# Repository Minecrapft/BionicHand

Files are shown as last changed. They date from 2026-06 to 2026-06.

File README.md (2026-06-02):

# Robohand

A simple Arduino sketch to control a robotic hand (servo-based) — provided as `Robohand.ino`.

## Summary

This project contains an Arduino sketch that reads inputs (sensors/buttons/potentiometers) and drives servos to move a robotic hand. Use this README to set up the hardware, upload the sketch, and customize pin mappings or servo ranges.

## Files

- `Robohand.ino` — main Arduino sketch (open in Arduino IDE).

## Required Hardware

- Arduino board (Uno, Nano, Mega, etc.)
- 3–5 x hobby servos (depending on hand design)
- Power supply for servos (separate 5–6V recommended)
- Jumper wires, breadboard
- Optional: potentiometers, push buttons, flex sensors for control

## Wiring (example)

- Connect servo signal wires to Arduino digital pins (example):
  - Thumb: D3
  - Index: D5
  - Middle: D6
  - Ring: D9
  - Pinky: D10
- Connect servo power (V+) and ground to the servo power supply. Connect servo ground to Arduino GND.
- Connect control inputs (potentiometers or buttons) to analog pins A0–A2 as needed.

Adjust pin numbers in `Robohand.ino` to match your wiring.

## Software & Upload

1. Install the Arduino IDE from https://arduino.cc.
2. Open `Robohand.ino` in the Arduino IDE.
3. Select the correct board and port under `Tools` → `Board` / `Port`.
4. Connect the Arduino via USB and click Upload.

If using external servo power, ensure the external supply is connected and common-grounded with the Arduino before powering servos.

## Usage

- Once uploaded, control the hand using the configured inputs (potentiometers/buttons). The sketch maps inputs to servo positions; modify the mapping in the code if needed.

## Customization

- Open `Robohand.ino` and edit pin definitions and servo limits to match your hardware.
- Calibrate servo min/max values to prevent mechanical binding.

## Troubleshooting

- Servos jittering: provide a stable external power supply and common ground.
- Servo not moving: check signal pin, correct power, and that the sketch references the correct pin.

## Contact

If you want help customizing the sketch or wiring, open an issue or reply here.

## ESP32-S3 (connection & run)

This sketch can run on an ESP32-S3-based board with a few small changes. Follow these steps to connect and upload:

1. Install ESP32 board support in the Arduino IDE:
  - Open `Tools` → `Board` → `Boards Manager` and install the "esp32" package by Espressif.
2. Power and wiring:
  - Servos typically need 5V. Use a separate 5–6V servo power supply and connect all grounds together (ESP32 GND ↔ servo power GND).
  - Connect each servo signal wire to a free ESP32-S3 GPIO. Example (change pins in the sketch to match):
    - Thumb: GPIO 18
    - Index: GPIO 19
    - Middle: GPIO 21
    - Ring: GPIO 22
    - Pinky: GPIO 23
  - Avoid pins reserved for flash/SPI (commonly GPIO6–GPIO11) and consult your board's pinout for S3-specific restrictions.
3. Library and code changes:
  - If `Robohand.ino` uses the AVR `Servo.h`, switch to an ESP32-compatible servo library such as `ESP32Servo` (install via Library Manager) or use a PWM/i2c driver (PCA9685) for many servos.
  - Update the pin definitions at the top of `Robohand.ino` to the GPIOs you wired.
  - Ensure servo pulse limits are appropriate for your servos (calibrate `min`/`max` values to avoid binding).
4. Uploading the sketch:
  - In Arduino IDE select `Tools` → `Board` → `ESP32S3 Dev Module` (or the specific board name) and the correct `Port`.
  - Click Upload. If required, press the boot/enable buttons as prompted by the IDE.
5. Troubleshooting & tips:
  - If servos twitch or reset the board, power them from a dedicated supply and keep a common ground.
  - For many servos, using a dedicated PWM driver (PCA9685) reduces load on the ESP32 and simplifies timing.
  - Use the Serial Monitor to view debug messages; set the baud rate in the sketch to match (commonly 115200).

These steps should get `Robohand.ino` running on an ESP32-S3 board. If you want, I can update `Robohand.ino` to include `ESP32Servo` examples and default ESP32 pin definitions.

## Control via Phone (Web Interface)

To control the robot hand from your phone using a web browser on the local network:

### Setup

1. **Connect ESP32-S3 to WiFi:**
   - Add WiFi credentials to `Robohand.ino`:
     ```cpp
     const char* ssid = "YOUR_WIFI_SSID";
     const char* password = "YOUR_WIFI_PASSWORD";
     ```
   - Initialize WiFi in `setup()`:
     ```cpp
     WiFi.begin(ssid, password);
     while (WiFi.status() != WL_CONNECTED) {
       delay(500);
     }
     Serial.println(WiFi.localIP());
     ```
   - Note the IP address printed to the Serial Monitor (e.g., `192.168.1.100`).

2. **Create a simple web server:**
   - Add these includes at the top of `Robohand.ino`:
     ```cpp
     #include <WiFi.h>
     #include <WebServer.h>
     ```
   - Create a WebServer instance:
     ```cpp
     WebServer server(80);  // Listen on port 80 (HTTP)
     ```
   - In `setup()`, define a handler that serves an HTML control panel:
     ```cpp
     server.on("/", HTTP_GET, []() {
       String html = "<html><body style='font-family:Arial'>"
         "<h1>Robohand Control</h1>"
         "<button onclick=\"fetch('/servo?pin=18&pos=90')\">Thumb Open</button>"
         "<button onclick=\"fetch('/servo?pin=18&pos=0')\">Thumb Close</button><br>"
         "<button onclick=\"fetch('/servo?pin=19&pos=90')\">Index Open</button>"
         "<button onclick=\"fetch('/servo?pin=19&pos=0')\">Index Close</button><br>"
         "</body></html>";
       server.send(200, "text/html", html);
     });
     ```
   - Add a servo control endpoint:
     ```cpp
     server.on("/servo", HTTP_GET, []() {
       int pin = server.arg("pin").toInt();
       int pos = server.arg("pos").toInt();
       // Attach servo and move to position
       // (details depend on your Servo library)
       server.send(200, "text/plain", "OK");
     });
     ```
   - Start the server in `setup()`:
     ```cpp
     server.begin();
     ```
   - In `loop()`, handle incoming requests:
     ```cpp
     server.handleClient();
     ```

3. **Access from your phone:**
   - Connect your device to the **`RoboHand-S3`** WiFi network (password: `12345678`).
   - Open a web browser and navigate to: **`http://192.168.4.1`**
   - No port number needed — it runs on port 80 (standard HTTP), so the browser uses it automatically.
   - You should see the Robohand control panel with buttons to open/close fingers.

4. **Customize the web interface:**
   - Add sliders for smooth servo control:
     ```html
     <input type="range" min="0" max="180" value="90" 
       onchange="fetch('/servo?pin=18&pos=' + this.value)">
     ```
   - Add visual feedback (color change, status display) using JavaScript.

### Troubleshooting

- **Phone can't find the ESP32:** Ensure both phone and ESP32-S3 are on the same WiFi network.
- **Web page doesn't load:** Check the IP address from the Serial Monitor (e.g., 192.168.1.), and make sure no firewall is blocking port 80.
- **Servos don't respond:** Verify the `/servo` endpoint is correctly wired to your servo control code.

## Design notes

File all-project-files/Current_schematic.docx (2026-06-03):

SCHEMATIC DIAGRAM

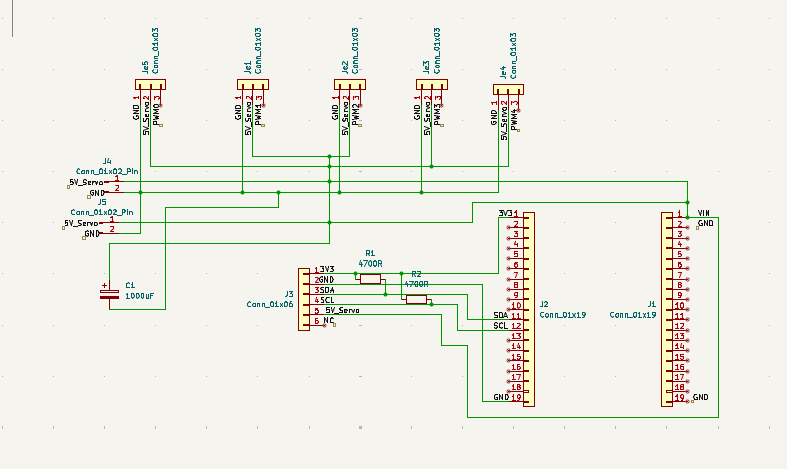
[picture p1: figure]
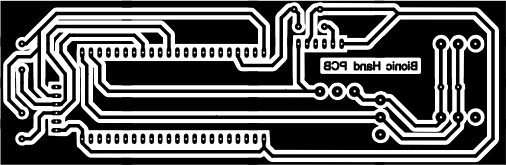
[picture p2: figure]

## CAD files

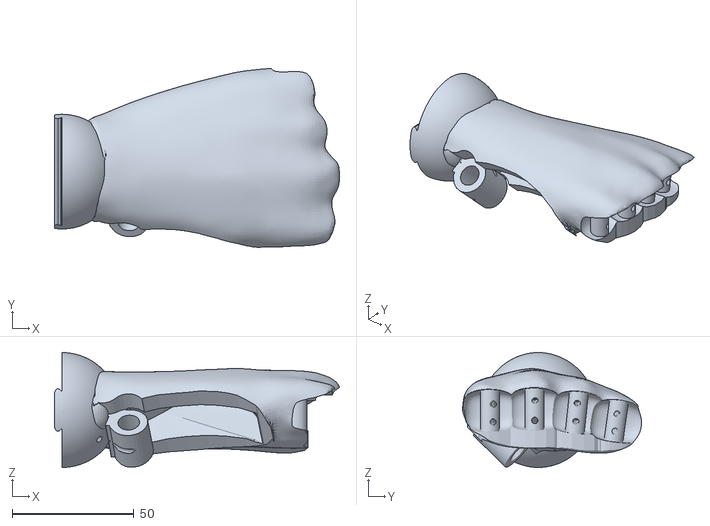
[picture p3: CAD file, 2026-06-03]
all-project-files/bionic_hand-stl-files/bionic_hand__1.stl
116.8 x 73.4 x 47.2

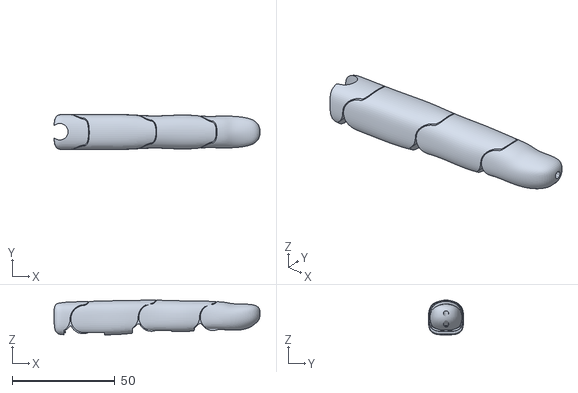
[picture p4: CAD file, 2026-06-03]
all-project-files/bionic_hand-stl-files/bionic_hand__13.stl
100.2 x 17.2 x 16.9

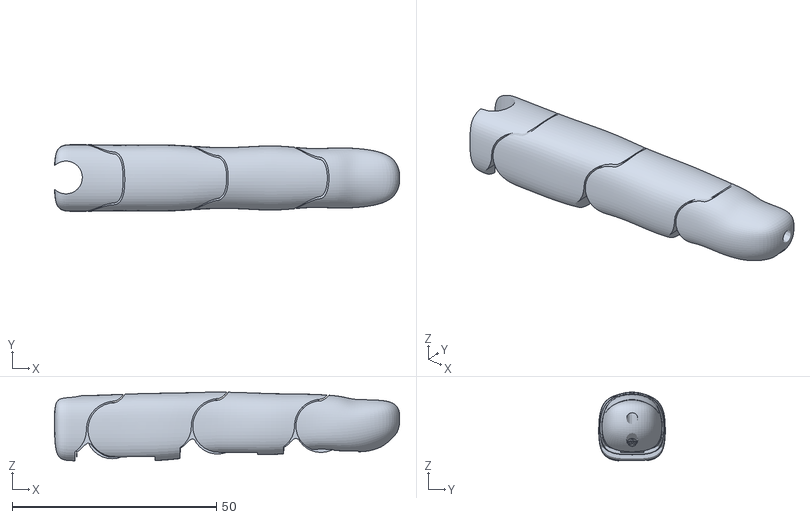
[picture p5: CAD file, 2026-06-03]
all-project-files/bionic_hand-stl-files/bionic_hand__16.stl
84.5 x 16.3 x 16.9

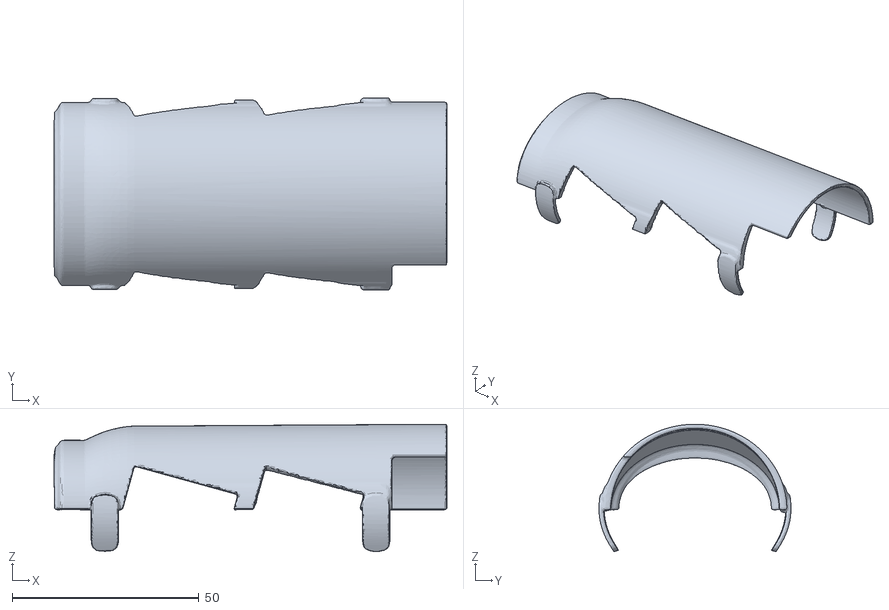
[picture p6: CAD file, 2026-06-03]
all-project-files/bionic_hand-stl-files/bionic_hand__3.stl
105.3 x 51.4 x 34.1

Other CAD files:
all-project-files/bionic_hand-stl-files/bionic_hand__14.stl
all-project-files/bionic_hand-stl-files/bionic_hand__15.stl

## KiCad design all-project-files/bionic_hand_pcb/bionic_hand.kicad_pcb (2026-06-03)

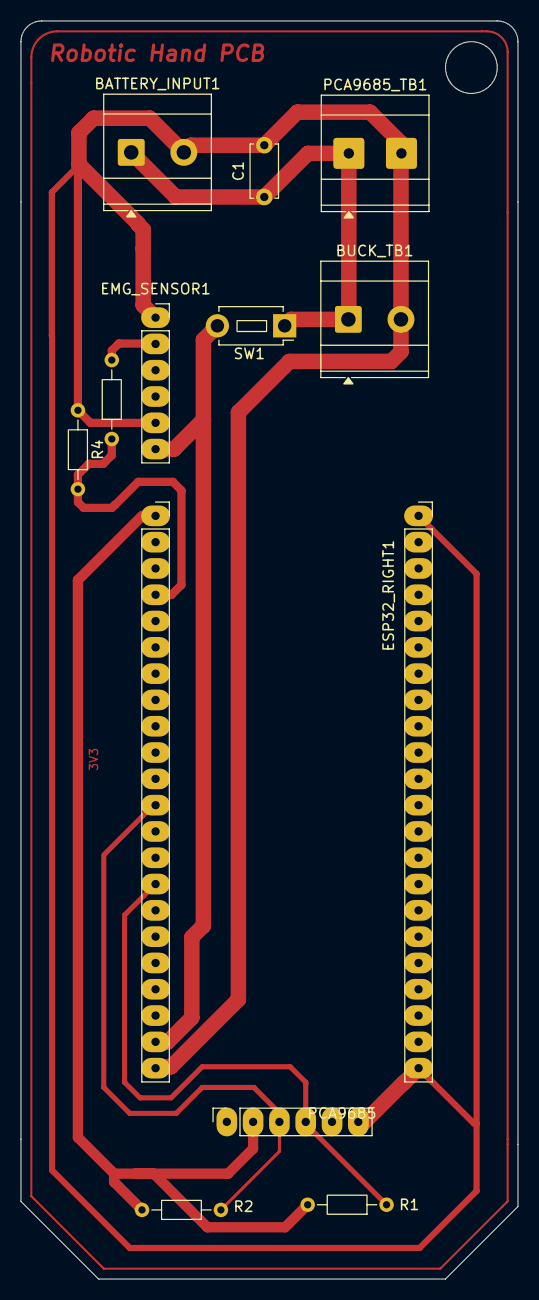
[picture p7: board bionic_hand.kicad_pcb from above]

Board: 2 copper layers, 48.0 x 121.5 mm, 13 parts (0 on the bottom side), 7 nets.

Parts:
BATTERY_INPUT1: Screw_Terminal_01x02; TerminalBlock_MetzConnect_Type073_RT02602HBLU_1x02_P5.08mm_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
BUCK_TB1: Screw_Terminal_01x02; TerminalBlock_MetzConnect_Type073_RT02602HBLU_1x02_P5.08mm_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
C1: 470u; C_Disc_D5.0mm_W2.5mm_P5.00mm
EMG_SENSOR1: Conn_01x06; PinSocket_1x06_P2.54mm_Vertical
ESP32_LEFT1, ESP32_RIGHT1: Conn_01x22; PinSocket_1x22_P2.54mm_Vertical
PCA9685: Conn_01x06; PinSocket_1x06_P2.54mm_Vertical
PCA9685_TB1: Screw_Terminal_01x02; TerminalBlock_MetzConnect_Type073_RT02602HBLU_1x02_P5.08mm_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
R1, R2, R3: 10k; R_Axial_DIN0204_L3.6mm_D1.6mm_P7.62mm_Horizontal
R4: 20k; R_Axial_DIN0204_L3.6mm_D1.6mm_P7.62mm_Horizontal
SW1: SW_DPST_x2; SW_PUSH_1P1T_6x3.5mm_H4.3_APEM_MJTP1243

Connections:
3V3: ESP32_LEFT1.1, PCA9685.2, R1.2, R2.2
5Vin: BATTERY_INPUT1.1, BUCK_TB1.1, C1.1, EMG_SENSOR1.6, ESP32_LEFT1.21, PCA9685_TB1.1, SW1.1 (A), SW1.2 (B)
/SIG: EMG_SENSOR1.2, R3.2
CMN_GND: BATTERY_INPUT1.2, BUCK_TB1.2, C1.2, EMG_SENSOR1.1, EMG_SENSOR1.5, ESP32_LEFT1.22, ESP32_RIGHT1.1, ESP32_RIGHT1.22, PCA9685.6, PCA9685_TB1.2, R4.1
GPIO4: ESP32_LEFT1.4, R3.1, R4.2
GPIO8: ESP32_LEFT1.12, PCA9685.3, R2.1
GPIO9: ESP32_LEFT1.15, PCA9685.4, R1.1

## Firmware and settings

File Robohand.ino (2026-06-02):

#include <Arduino.h>
#include <WiFi.h>
#include <WebServer.h>
#include <Preferences.h>
#include <Wire.h>
#include <Adafruit_PWMServoDriver.h>

#define NUM_SERVOS   5
#define MAX_PRESETS  16   // max stored presets
#define MAX_STEPS    20   // max steps per preset

const char* ssid     = "RoboHand-S3";
const char* password = "12345678";

Adafruit_PWMServoDriver pwm = Adafruit_PWMServoDriver(0x40);

int  currentAngles[NUM_SERVOS]      = {0,   0,   0,   0,   0};
int  calibrationOffsets[NUM_SERVOS] = {0,   0,   0,   0,   0};

int  servoMin[NUM_SERVOS]           = {150, 150, 150, 150, 150};
int  servoMax[NUM_SERVOS]           = {600, 600, 600, 600, 600};
int  servoMaxAngle[NUM_SERVOS]      = {180, 180, 180, 180, 180};
int  servoSpeed[NUM_SERVOS]         = {0, 0, 0, 0, 0};
bool servoReversed[NUM_SERVOS]      = {false, false, false, false, false};
char servoLabels[NUM_SERVOS][16]    = {"Thumb","Index","Middle","Ring","Pinky"};

float currentPhysicalAngles[NUM_SERVOS] = {0, 0, 0, 0, 0};
unsigned long lastUpdateTime = 0;

// ── Preset data structures ──────────────────────────────────────────────────
struct PresetStep {
  int  angles[NUM_SERVOS]; // target angle for each servo
  int  speed;              // deg/sec for this step (0 = instant)
  int  holdMs;             // how long to hold after reaching position (ms)
};

struct Preset {
  bool       used;
  char       name[24];
  int        stepCount;
  PresetStep steps[MAX_STEPS];
};

Preset presets[MAX_PRESETS];

// ── Preset playback state ───────────────────────────────────────────────────
bool     presetRunning    = false;
int      presetRunId      = -1;
int      presetRunStep    = -1;
unsigned long presetHoldEnd = 0;        // millis when current hold expires
bool     presetMoving     = false;      // waiting for servos to reach target
int      presetSpeedOverride[NUM_SERVOS]; // per-step speed stored here
int      presetTargets[NUM_SERVOS];       // current step's angle targets

WebServer server(80);
Preferences prefs;

// ══════════════════════════════════════════════════════════════════════════════
//  HTML / CSS / JS  (single embedded page)
// ══════════════════════════════════════════════════════════════════════════════
const char INDEX_HTML[] = R"rawliteral(
<!DOCTYPE html>
<html lang="en">
<head>
<meta charset="UTF-8"/>
<meta name="viewport" content="width=device-width,initial-scale=1,user-scalable=no"/>
<title>RoboHand Controller</title>
<style>
:root{--bg:#05111f;--s1:#0d1f35;--s2:#152840;--ac:#00d4ff;--pu:#7c3aed;--tx:#e2e8f0;--mu:#64748b;--ok:#22c55e;--er:#ef4444;--wa:#f59e0b;--bd:#1e3a5f}
*{box-sizing:border-box;margin:0;padding:0;-webkit-tap-highlight-color:transparent}
body{font-family:-apple-system,BlinkMacSystemFont,'Segoe UI',sans-serif;background:var(--bg);color:var(--tx);min-height:100vh}
.hdr{background:linear-gradient(135deg,var(--s1),var(--s2));padding:16px 20px;display:flex;align-items:center;justify-content:space-between;border-bottom:1px solid var(--bd);position:sticky;top:0;z-index:99}
.hdr-title{font-size:20px;font-weight:800;background:linear-gradient(135deg,var(--ac),var(--pu));-webkit-background-clip:text;-webkit-text-fill-color:transparent;background-clip:text}
.hdr-sub{font-size:12px;color:var(--mu);display:flex;align-items:center;gap:6px}
.dot{width:8px;height:8px;border-radius:50%;background:var(--ok);animation:blink 2s infinite;display:inline-block}
@keyframes blink{0%,100%{opacity:1}50%{opacity:.3}}
.tabs{display:flex;background:var(--s1);border-bottom:1px solid var(--bd);overflow-x:auto}
.tab{flex:1;min-width:70px;padding:14px 8px;text-align:center;font-size:13px;font-weight:600;color:var(--mu);cursor:pointer;border-bottom:3px solid transparent;transition:.2s;white-space:nowrap}
.tab.on{color:var(--ac);border-color:var(--ac)}
.pane{display:none}.pane.on{display:block}
.wrap{padding:14px;max-width:560px;margin:0 auto}
/* ── Quick Actions ── */
.qa{display:grid;grid-template-columns:repeat(3,1fr);gap:10px;margin-bottom:16px}
.qb{background:var(--s1);border:1px solid var(--bd);border-radius:16px;padding:14px 8px;text-align:center;cursor:pointer;transition:.15s;user-select:none}
.qb:active{transform:scale(.93);background:var(--s2)}
.qb .ico{font-size:26px;line-height:1.2}
.qb .lbl{font-size:11px;font-weight:600;color:var(--mu);margin-top:4px}
.qb.hi{border-color:var(--ac)}.qb.hi .lbl{color:var(--ac)}
/* ── Finger cards ── */
.fc{display:flex;flex-direction:column;gap:12px}
.fcard{background:var(--s1);border:2px solid var(--bd);border-radius:20px;padding:18px;transition:border-color .3s}
.fcard.lit{border-color:var(--ac)}
.fhdr{display:flex;align-items:center;justify-content:space-between;margin-bottom:14px}
.fbadge{width:36px;height:36px;border-radius:10px;display:flex;align-items:center;justify-content:center;font-weight:800;font-size:15px;color:#fff;flex-shrink:0;margin-right:10px}
.fname{font-size:16px;font-weight:700}
.fsub{font-size:12px;color:var(--mu);margin-top:2px}
.anum{font-size:24px;font-weight:800;color:var(--ac);min-width:56px;text-align:right}
input[type=range]{-webkit-appearance:none;appearance:none;width:100%;height:8px;background:var(--s2);border-radius:999px;outline:none;margin:6px 0;display:block}
input[type=range]::-webkit-slider-thumb{-webkit-appearance:none;width:28px;height:28px;border-radius:50%;background:linear-gradient(135deg,var(--ac),var(--pu));cursor:pointer;box-shadow:0 0 10px #00d4ff55}
input[type=range]:active::-webkit-slider-thumb{box-shadow:0 0 20px #00d4ffaa}
.row{display:flex;align-items:center;gap:10px;margin-top:10px}
.sbtn{width:44px;height:44px;border-radius:12px;border:1px solid var(--bd);background:var(--s2);color:var(--tx);font-size:22px;font-weight:700;cursor:pointer;display:flex;align-items:center;justify-content:center;transition:.15s;flex-shrink:0;user-select:none;line-height:1}
.sbtn:active{background:var(--ac);color:#000}
.hint{flex:1;text-align:center;color:var(--mu);font-size:11px}
/* ── Calibrate ── */
.ccard{background:var(--s1);border:1px solid var(--bd);border-radius:18px;padding:18px;margin-bottom:12px}
.chdr{display:flex;align-items:center;justify-content:space-between;margin-bottom:12px}
.cname{font-weight:600;font-size:15px}
.obadge{border-radius:8px;padding:5px 12px;font-size:14px;font-weight:700;background:var(--s2);color:var(--mu)}
.obadge.pos{color:var(--ok)}.obadge.neg{color:var(--er)}
.rst{width:100%;padding:16px;background:linear-gradient(135deg,var(--ac),var(--pu));border:none;border-radius:14px;color:#fff;font-weight:700;font-size:16px;cursor:pointer;margin-top:4px}
.rst:active{opacity:.8}
/* ── Config ── */
.cfcard{background:var(--s1);border:1px solid var(--bd);border-radius:18px;padding:18px;margin-bottom:12px}
.cfhdr{display:flex;align-items:center;gap:10px;margin-bottom:14px}
.fl{font-size:11px;color:var(--mu);font-weight:600;margin-bottom:5px}
.tinp{width:100%;padding:10px 12px;background:var(--s2);border:1px solid var(--bd);border-radius:10px;color:var(--tx);font-size:14px;outline:none;margin-bottom:12px}
.tinp:focus{border-color:var(--ac)}
.g2{display:grid;grid-template-columns:1fr 1fr;gap:10px;margin-bottom:12px}
.ninp{width:100%;padding:10px 8px;background:var(--s2);border:1px solid var(--bd);border-radius:10px;color:var(--tx);font-size:14px;outline:none;text-align:center}
.ninp:focus{border-color:var(--ac)}
.trow{display:flex;align-items:center;justify-content:space-between;margin-bottom:14px}
.trow span{font-size:14px}
.togbtn{padding:7px 16px;border-radius:8px;border:1px solid var(--bd);background:var(--s2);color:var(--mu);font-size:13px;font-weight:600;cursor:pointer;transition:.2s}
.togbtn.on{background:var(--ac);color:#000;border-color:var(--ac)}
.scfg{width:100%;padding:13px;background:linear-gradient(135deg,var(--ac),var(--pu));border:none;border-radius:12px;color:#fff;font-weight:700;font-size:14px;cursor:pointer}
.scfg:active{opacity:.8}
/* ══ PRESETS TAB ══════════════════════════════════════════════════════════ */
.pst-toprow{display:flex;gap:10px;margin-bottom:14px;margin-top:14px}
.pst-newbtn{flex:1;padding:13px;background:linear-gradient(135deg,var(--ac),var(--pu));border:none;border-radius:14px;color:#fff;font-weight:700;font-size:14px;cursor:pointer}
.pst-newbtn:active{opacity:.8}
.pst-list{display:flex;flex-direction:column;gap:10px}
.pst-card{background:var(--s1);border:1px solid var(--bd);border-radius:18px;padding:16px;display:flex;align-items:center;gap:12px}
.pst-card.running{border-color:var(--ok);box-shadow:0 0 12px #22c55e33}
.pst-icon{width:44px;height:44px;border-radius:12px;background:var(--s2);display:flex;align-items:center;justify-content:center;font-size:22px;flex-shrink:0}
.pst-info{flex:1;min-width:0}
.pst-name{font-weight:700;font-size:15px;white-space:nowrap;overflow:hidden;text-overflow:ellipsis}
.pst-meta{font-size:11px;color:var(--mu);margin-top:3px}
.pst-btns{display:flex;gap:7px;flex-shrink:0}
.ic-btn{width:38px;height:38px;border-radius:10px;border:1px solid var(--bd);background:var(--s2);color:var(--tx);font-size:17px;cursor:pointer;display:flex;align-items:center;justify-content:center;transition:.15s}
.ic-btn:active{opacity:.7}
.ic-btn.run{background:#0f3d1a;border-color:var(--ok);color:var(--ok)}
.ic-btn.edit{background:#0d2040;border-color:var(--ac);color:var(--ac)}
.ic-btn.del{background:#3d0f0f;border-color:var(--er);color:var(--er)}
.ic-btn.stop{background:#3d1f00;border-color:var(--wa);color:var(--wa)}
/* ── Preset Editor ── */
.pe-back{display:flex;align-items:center;gap:8px;margin-bottom:14px;cursor:pointer;color:var(--ac);font-weight:600;font-size:14px;margin-top:14px}
.pe-back:active{opacity:.7}
.pe-namebox{background:var(--s1);border:1px solid var(--bd);border-radius:16px;padding:16px;margin-bottom:12px}
.pe-steps{display:flex;flex-direction:column;gap:10px;margin-bottom:12px}
.step-card{background:var(--s1);border:2px solid var(--bd);border-radius:18px;padding:16px;position:relative}
.step-card.active-step{border-color:var(--ok)}
.step-hdr{display:flex;align-items:center;justify-content:space-between;margin-bottom:12px}
.step-num{width:30px;height:30px;border-radius:8px;background:var(--pu);display:flex;align-items:center;justify-content:center;font-weight:800;font-size:13px;color:#fff;flex-shrink:0}
.step-title{font-weight:700;font-size:14px;flex:1;margin-left:8px}
.step-del{width:30px;height:30px;border-radius:8px;border:1px solid var(--er);background:#3d0f0f;color:var(--er);font-size:16px;cursor:pointer;display:flex;align-items:center;justify-content:center}
.step-del:active{opacity:.6}
.step-grid{display:grid;grid-template-columns:1fr 1fr;gap:8px;margin-bottom:10px}
.sg-cell{background:var(--s2);border:1px solid var(--bd);border-radius:10px;padding:10px;display:flex;flex-direction:column;gap:4px}
.sg-lbl{font-size:10px;color:var(--mu);font-weight:600}
.sg-val{font-size:18px;font-weight:800;color:var(--ac);text-align:center}
.sg-rng{width:100%;-webkit-appearance:none;appearance:none;height:6px;background:var(--bg);border-radius:999px;outline:none}
.sg-rng::-webkit-slider-thumb{-webkit-appearance:none;width:22px;height:22px;border-radius:50%;background:linear-gradient(135deg,var(--ac),var(--pu));cursor:pointer}
.step-timing{display:grid;grid-template-columns:1fr 1fr;gap:8px}
.st-cell{background:var(--s2);border:1px solid var(--bd);border-radius:10px;padding:10px}
.st-lbl{font-size:10px;color:var(--mu);font-weight:600;margin-bottom:4px}
.st-inp{width:100%;background:transparent;border:none;color:var(--tx);font-size:16px;font-weight:700;text-align:center;outline:none}
.add-step-btn{width:100%;padding:13px;background:var(--s1);border:2px dashed var(--bd);border-radius:14px;color:var(--mu);font-weight:600;font-size:14px;cursor:pointer;transition:.2s}
.add-step-btn:hover{border-color:var(--ac);color:var(--ac)}
.add-step-btn:active{opacity:.7}
.pe-save{width:100%;padding:15px;background:linear-gradient(135deg,var(--ac),var(--pu));border:none;border-radius:14px;color:#fff;font-weight:700;font-size:16px;cursor:pointer;margin-top:6px}
.pe-save:active{opacity:.8}
.pe-run{width:100%;padding:13px;background:linear-gradient(135deg,#166534,#15803d);border:none;border-radius:14px;color:#fff;font-weight:700;font-size:14px;cursor:pointer;margin-top:8px}
.pe-run:active{opacity:.8}
/* step move arrows */
.step-arrows{display:flex;gap:4px}
.arr-btn{width:26px;height:26px;border-radius:6px;border:1px solid var(--bd);background:var(--s2);color:var(--mu);font-size:13px;cursor:pointer;display:flex;align-items:center;justify-content:center}
.arr-btn:active{background:var(--ac);color:#000}
/* status pill */
.status-pill{position:fixed;bottom:18px;left:50%;transform:translateX(-50%);background:var(--s1);border:1px solid var(--bd);border-radius:999px;padding:8px 20px;font-size:13px;font-weight:600;color:var(--mu);transition:.3s;z-index:200;pointer-events:none;opacity:0}
.status-pill.show{opacity:1}
.status-pill.ok{border-color:var(--ok);color:var(--ok)}
.status-pill.er{border-color:var(--er);color:var(--er)}
.status-pill.ru{border-color:var(--wa);color:var(--wa)}
</style>
</head>
<body>
<div class="hdr">
  <div class="hdr-title">&#129302; RoboHand</div>
  <div class="hdr-sub"><span class="dot"></span>192.168.4.1</div>
</div>
<div class="tabs">
  <div class="tab on"  id="tab-ctrl" onclick="sw('ctrl')">&#9654; Control</div>
  <div class="tab"     id="tab-pst"  onclick="sw('pst')">&#127381; Presets</div>
  <div class="tab"     id="tab-cal"  onclick="sw('cal')">&#9881; Calibrate</div>
  <div class="tab"     id="tab-cfg"  onclick="sw('cfg')">&#9965; Configure</div>
</div>

<!-- ════ CONTROL PANE ════ -->
<div id="pane-ctrl" class="pane on">
  <div class="wrap">
    <div class="qa" style="margin-top:14px">
      <div class="qb" onclick="setAll(0)"><div class="ico">&#x270A;</div><div class="lbl">Fist 0&#176;</div></div>
      <div class="qb hi" onclick="setAll(90)"><div class="ico">&#x1F590;</div><div class="lbl">Home 90&#176;</div></div>
      <div class="qb" onclick="setAll(180)"><div class="ico">&#x1F44B;</div><div class="lbl">Open 180&#176;</div></div>
    </div>
    <div class="fc" id="fingerCards"></div>
  </div>
</div>

<!-- ════ PRESETS PANE ════ -->
<div id="pane-pst" class="pane">
  <div id="pst-list-view">
    <div class="wrap">
      <div class="pst-toprow">
        <button class="pst-newbtn" onclick="newPreset()">&#43; New Preset</button>
      </div>
      <div class="pst-list" id="pstList"></div>
    </div>
  </div>
  <div id="pst-editor-view" style="display:none">
    <div class="wrap">
      <div class="pe-back" onclick="closeEditor()">&#8592; Back to Presets</div>
      <div class="pe-namebox">
        <div class="fl">Preset Name</div>
        <input type="text" class="tinp" id="pe-name" maxlength="23" placeholder="e.g. Wave Hello" style="margin-bottom:0"/>
      </div>
      <div class="pe-steps" id="peSteps"></div>
      <button class="add-step-btn" onclick="addStep()">&#43; Add Step</button>
      <button class="pe-save" onclick="savePreset()" style="margin-top:14px">&#10003; Save Preset</button>
      <button class="pe-run"  onclick="runEditorPreset()">&#9654; Save &amp; Run</button>
    </div>
  </div>
</div>

<!-- ════ CALIBRATE PANE ════ -->
<div id="pane-cal" class="pane">
  <div class="wrap">
    <div style="margin-top:14px" id="calCards"></div>
    <button class="rst" onclick="resetOffsets()">&#8635; Reset All Offsets to 0</button>
  </div>
</div>

<!-- ════ CONFIGURE PANE ════ -->
<div id="pane-cfg" class="pane">
  <div class="wrap" style="margin-top:14px" id="cfgCards"></div>
</div>

<div class="status-pill" id="statusPill"></div>

<script>
var NAMES  = ["Thumb","Index","Middle","Ring","Pinky"];
var COLORS = ["#00d4ff","#7c3aed","#10b981","#f59e0b","#f43f5e"];
var ABBR   = ["T","I","M","R","P"];
var MAX_ANGLES = [180,180,180,180,180];
var state  = {angles:[0,0,0,0,0], offsets:[0,0,0,0,0]};
var tmr    = null;
var revState = [false,false,false,false,false];

// ── Preset editor state ──────────────────────────────────────────────────────
var editingId  = -1;     // -1 = new preset
var editSteps  = [];     // array of {angles:[5], speed:int, holdMs:int}
var runningId  = -1;

// ════════════════════════════════════════════════════════════════════════════
//  TAB SWITCHER
// ════════════════════════════════════════════════════════════════════════════
function sw(name){
  ['ctrl','pst','cal','cfg'].forEach(function(t){
    document.getElementById('tab-'+t).classList.toggle('on',t===name);
    document.getElementById('pane-'+t).classList.toggle('on',t===name);
  });
  if(name==='pst') loadPresetList();
}
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
void loop() {
  server.handleClient();

  unsigned long now = millis();
  unsigned long dt  = now - lastUpdateTime;
  if (dt == 0) { delay(5); return; }
  lastUpdateTime = now;

  // ── Preset playback ────────────────────────────────────────────────────────
  if (presetRunning && presetRunId >= 0) {
    Preset &p = presets[presetRunId];

    if (presetMoving) {
      // Drive servos toward presetTargets using presetSpeedOverride per servo
      bool allDone = true;
      for (int i = 0; i < NUM_SERVOS; i++) {
        int target = presetTargets[i];
        int spd    = presetSpeedOverride[i];
        if (spd <= 0) {
          currentPhysicalAngles[i] = target;
        } else {
          float step = (spd * dt) / 1000.0f;
          if (currentPhysicalAngles[i] < target) {
            currentPhysicalAngles[i] = min((float)target, currentPhysicalAngles[i] + step);
          } else {
            currentPhysicalAngles[i] = max((float)target, currentPhysicalAngles[i] - step);
          }
        }
        pwm.setPWM(i, 0, angleToPulse(i, currentPhysicalAngles[i]));
        if (abs(currentPhysicalAngles[i] - target) > 0.5f) allDone = false;
      }
      if (allDone) {
        presetMoving  = false;
        presetHoldEnd = now + p.steps[presetRunStep].holdMs;
        // Sync logical angles
        for (int i = 0; i < NUM_SERVOS; i++)
          currentAngles[i] = presetTargets[i];
      }
    } else {
      // Holding — wait for hold time then advance to next step
      if (now >= presetHoldEnd) {
        int next = presetRunStep + 1;
        if (next < p.stepCount) {
          startPresetStep(presetRunId, next);
        } else {
          presetRunning = false;
          presetRunId   = -1;
          presetRunStep = -1;
        }
      }
    }
    delay(10);
    return; // skip normal servo update while running preset
  }

  // ── Normal servo update ────────────────────────────────────────────────────
  for (int i = 0; i < NUM_SERVOS; i++) {
    int target = constrain(currentAngles[i] + calibrationOffsets[i], 0, servoMaxAngle[i]);
    if (servoSpeed[i] <= 0) {
      if (currentPhysicalAngles[i] != target) {
        currentPhysicalAngles[i] = target;
        pwm.setPWM(i, 0, angleToPulse(i, currentPhysicalAngles[i]));
      }
    } else {
      if (abs(currentPhysicalAngles[i] - target) > 0.1f) {
        float step = (servoSpeed[i] * dt) / 1000.0f;
        currentPhysicalAngles[i] += (currentPhysicalAngles[i] < target ? step : -step);
        if ((step > 0 && currentPhysicalAngles[i] > target) ||
            (step < 0 && currentPhysicalAngles[i] < target))
          currentPhysicalAngles[i] = target;
        pwm.setPWM(i, 0, angleToPulse(i, currentPhysicalAngles[i]));
      } else if (currentPhysicalAngles[i] != target) {
        currentPhysicalAngles[i] = target;
        pwm.setPWM(i, 0, angleToPulse(i, currentPhysicalAngles[i]));
      }
    }
  }
  delay(10);
}

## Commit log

2026-06-02 Update README.md for project details and ESP32 support
2026-06-03 added the files
    [bionic_hand.kicad_pcb, bionic_hand.kicad_sch, bionic_hand__1.stl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]
